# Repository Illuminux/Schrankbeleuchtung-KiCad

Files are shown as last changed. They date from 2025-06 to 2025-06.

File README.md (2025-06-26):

# 💡 Schrankbeleuchtung

Automatisierte LED-Beleuchtung für Schränke, basierend auf einem Raspberry Pi Pico W. Türsensoren aktivieren bei Öffnung die zugeordneten LED-Gruppen über MOSFET-Schaltungen.

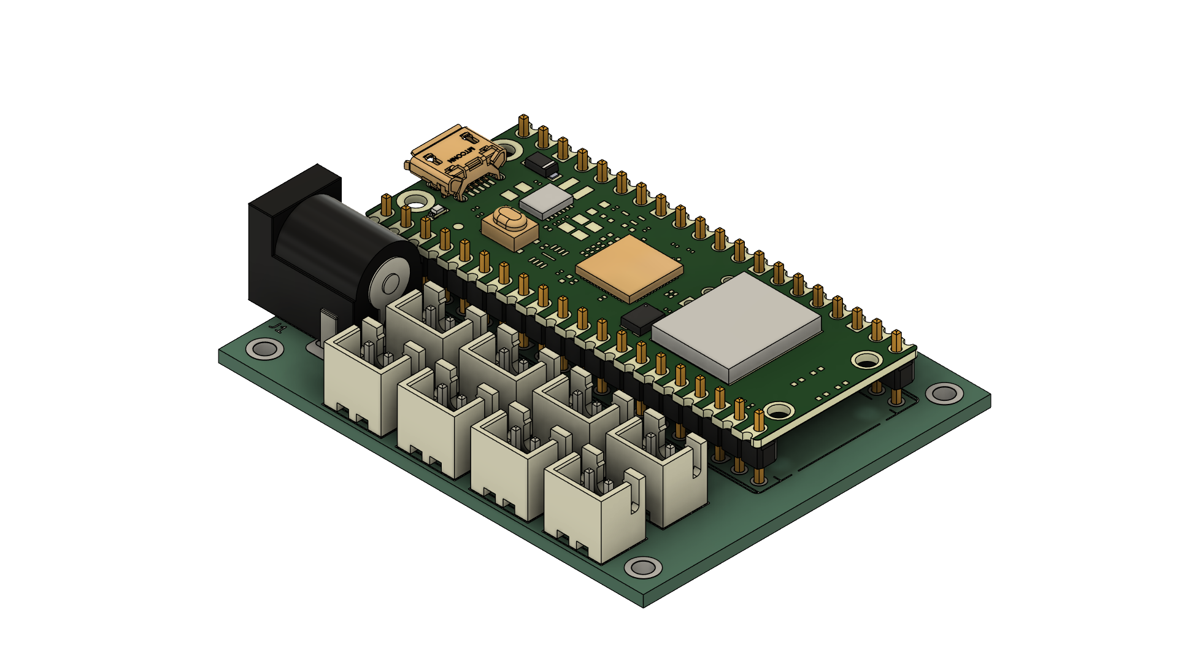
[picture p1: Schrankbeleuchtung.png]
Schaltplanübersicht


---

## 🧩 Features

- Bis zu 4 separat schaltbare LED-Gruppen
- Automatische Steuerung über Magnetsensoren oder Reed-Schalter
- Versorgung mit 12 V DC, intern auf 5 V und 3.3 V geregelt
- Geringe Standby-Leistung durch Low-RDS(on)-MOSFETs
- Erweiterbare Anschlüsse über XH-Steckerleisten

---

## 🔌 GPIO-Belegung (Pico W)

| Funktion | GPIO |
|---|---|
| LED 1 (Q1) | GPIO02 |
| LED 2 (Q2) | GPIO04 |
| LED 3 (Q3) | GPIO05 |
| LED 4 (Q4) | GPIO06 |
| Sensor 1 | GPIO06 |
| Sensor 2 | GPIO07 |
| Sensor 3 | GPIO14 |
| Sensor 4 | GPIO15 |

---

## 🛠 Komponenten (Auszug)

| Bauteil | Typ / Wert | Bestellnummer (Mouser)  |
|---|---|---|
| A1 | Raspberry Pi Pico W | 358-SC0918 |
| U1 | TPS560430XDBVT | 595-TPS560430XDBVT |
| Q1–Q4 | IRLML0030TRPBF | 942-IRLML0030TRPBF |
| R1–R4 | 187 Ω Widerstände | 667-ERA-6AEB1870V |
| R5–R9 | 10 kΩ Pull-Ups | 667-ERA-6APB103V |
| C1–C3 | 10 µF / 22 µF / 0.1 µF  | siehe BOM |
| L1 | 10 µH Spule | 81-LQH44PN100MPRL |
| J2–J9 | XH-Stecker + Buchsen | 306-B2B-XH-AMLFSNP |

Die vollständige Stückliste befindet sich in [Schrankbeleuchtung.xlsx](Schrankbeleuchtung.xlsx)

---

## ⚙️ Inbetriebnahme

1. Platine bestücken (nach Schaltplan aus *Schrankbeleuchtung.pdf*)
2. 12 V Versorgung an J1 anschließen
3. Türsensoren an J2–J5, LEDs an J6–J9 verbinden
4. Firmware auf Pico W flashen (z. B. mit MicroPython)
5. Funktion testen – bei Türöffnung sollten zugehörige LEDs leuchten

---

## 🧠 Firmware-Hinweise

Die Firmware sollte:

- LED-GPIOs als Output setzen
- Sensor-GPIOs mit Pull-Up und Debounce abfragen
- Bei erkanntem Öffnungssignal LEDs aktivieren
- Optional: MQTT-/WLAN-Anbindung via Pico W realisieren

---

## ⚖️ Lizenz

Dieses Projekt steht unter der MIT-Lizenz. Feel free to modify, use & share!

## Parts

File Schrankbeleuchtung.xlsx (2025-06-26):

Reference | Qty | Value | Part No | Mouser
 |  |  |  | Order No | Price / Pice | Price
A1 | 1 | RPiPicoW | SC0918 | 358-SC0918 | 5.70 € | 5.70 €
C1 | 1 | 10µF | GRM21BZ71E106KE5K | 81-GRM21BZ71E106KE5K | 0.30 € | 0.30 €
C2 | 1 | 22µF | GRM21BZ71A226ME5L | 81-GRM21BZ71A226ME5L | 0.27 € | 0.27 €
C3 | 1 | 0.1µF | 0805ZC104JAT2A | 581-0805ZC104JAT2A | 0.27 € | 0.27 €
J1 | 1 | Jack-DC | 694106301002 | 710-694106301002 | 0.87 € | 0.87 €
J2,J3,J4,J5,J6,J7,J8,J9 | 8 | Conn_01x02 | B2B-XH-AMLFSNP | 306-B2B-XH-AMLFSNP | 0.11 € | 0.88 €
L1 | 1 | LQH44PN100MPRL | LQH44PN100MPRL | 81-LQH44PN100MPRL | 0.42 € | 0.42 €
Q1,Q2,Q3,Q4 | 4 | IRLML0030TRPBF | IRLML0030TRPBF | 942-IRLML0030TRPBF | 0.33 € | 1.33 €
R1,R2,R3,R4 | 4 | 187R | ERA-6AEB1870V | 667-ERA-6AEB1870V | 0.09 € | 0.36 €
R5,R6,R7,R8,R9 | 5 | 10k | ERA-6APB103V | 667-ERA-6APB103V | 0.32 € | 1.60 €
R10 | 1 | 3.16k | NT0805DRD073K16L | 603-NT0805DRD073K16L | 0.53 € | 0.53 €
U1 | 1 | TPS560430XDBVT | TPS560430XDBVT | 595-TPS560430XDBVT | 1.25 € | 1.25 €
 |  |  |  | 1St |  | 13.78 €
 |  |  |  | 10 St |  | 129.65 €
Reference | Qty | Value | Part No | Mouser | Price / Pice | Price
J2',J3',J4',J5',J6',J7',J8',J9' | 8 | Buchse | XHP-2 | 306-XHP-2 | 0.10 € | 0.80 €
J2',J3'',J4'',J5'',J6'',J7'',J8'',J9'' | 8 | Pins | SEH-001T-P0.6 | 306-SEH-001T-P0.6 | 0.10 € | 0.80 €
A1' | 2 | Sockel | 68000-220HLF | 649-68000-220HLF | 1.04 € | 2.08 €
 |  |  |  |  |  | 3.68 €
 |  |  |  |  |  | 24.20 €
 |  |  |  |  |  | 17.46 €
 |  |  |  |  |  | 153.85 €
Versand |  |  |  |  |  | 0.00 €
PCB | 1 |  |  |  | 14.80 € | 14.80 €
Schablone | 1 |  |  |  | 9.90 € | 9.90 €
 |  |  |  |  |  | 24.70 €
 |  |  |  |  |  | 28.38 €

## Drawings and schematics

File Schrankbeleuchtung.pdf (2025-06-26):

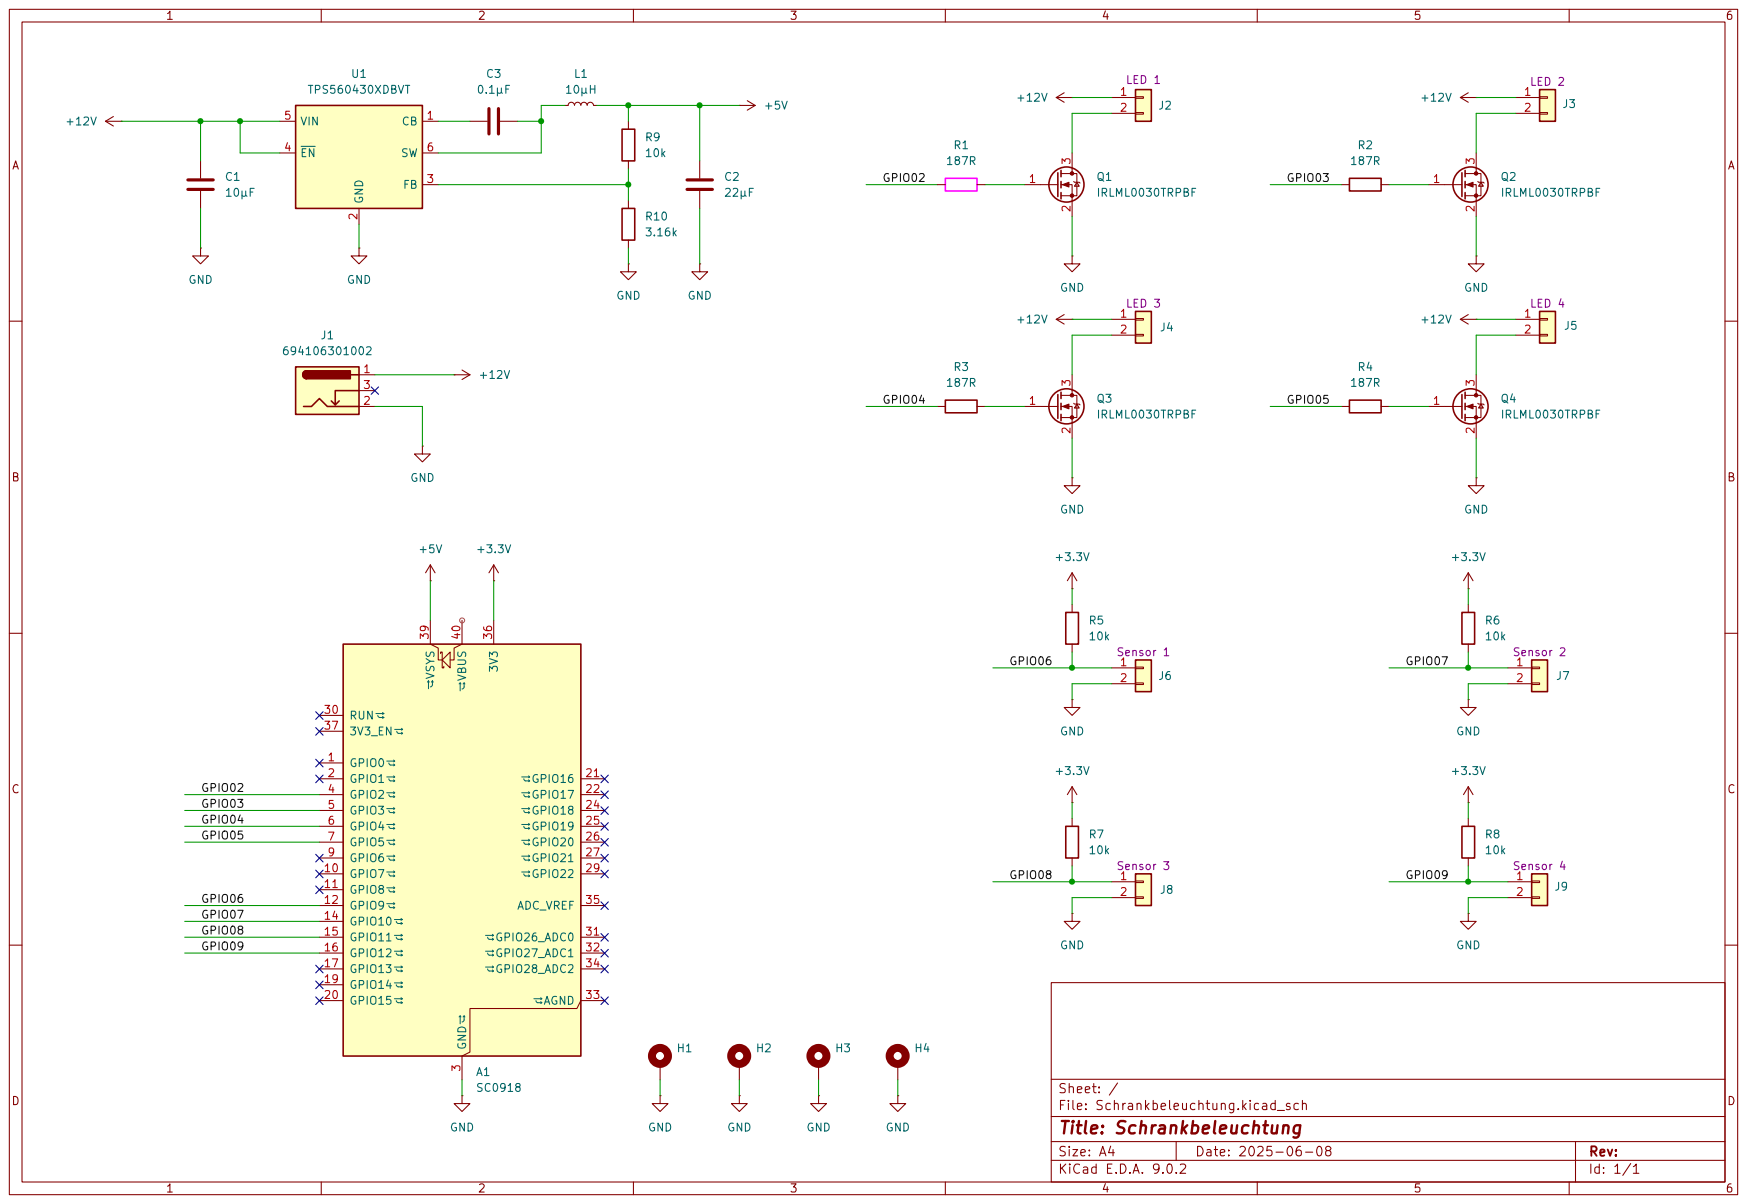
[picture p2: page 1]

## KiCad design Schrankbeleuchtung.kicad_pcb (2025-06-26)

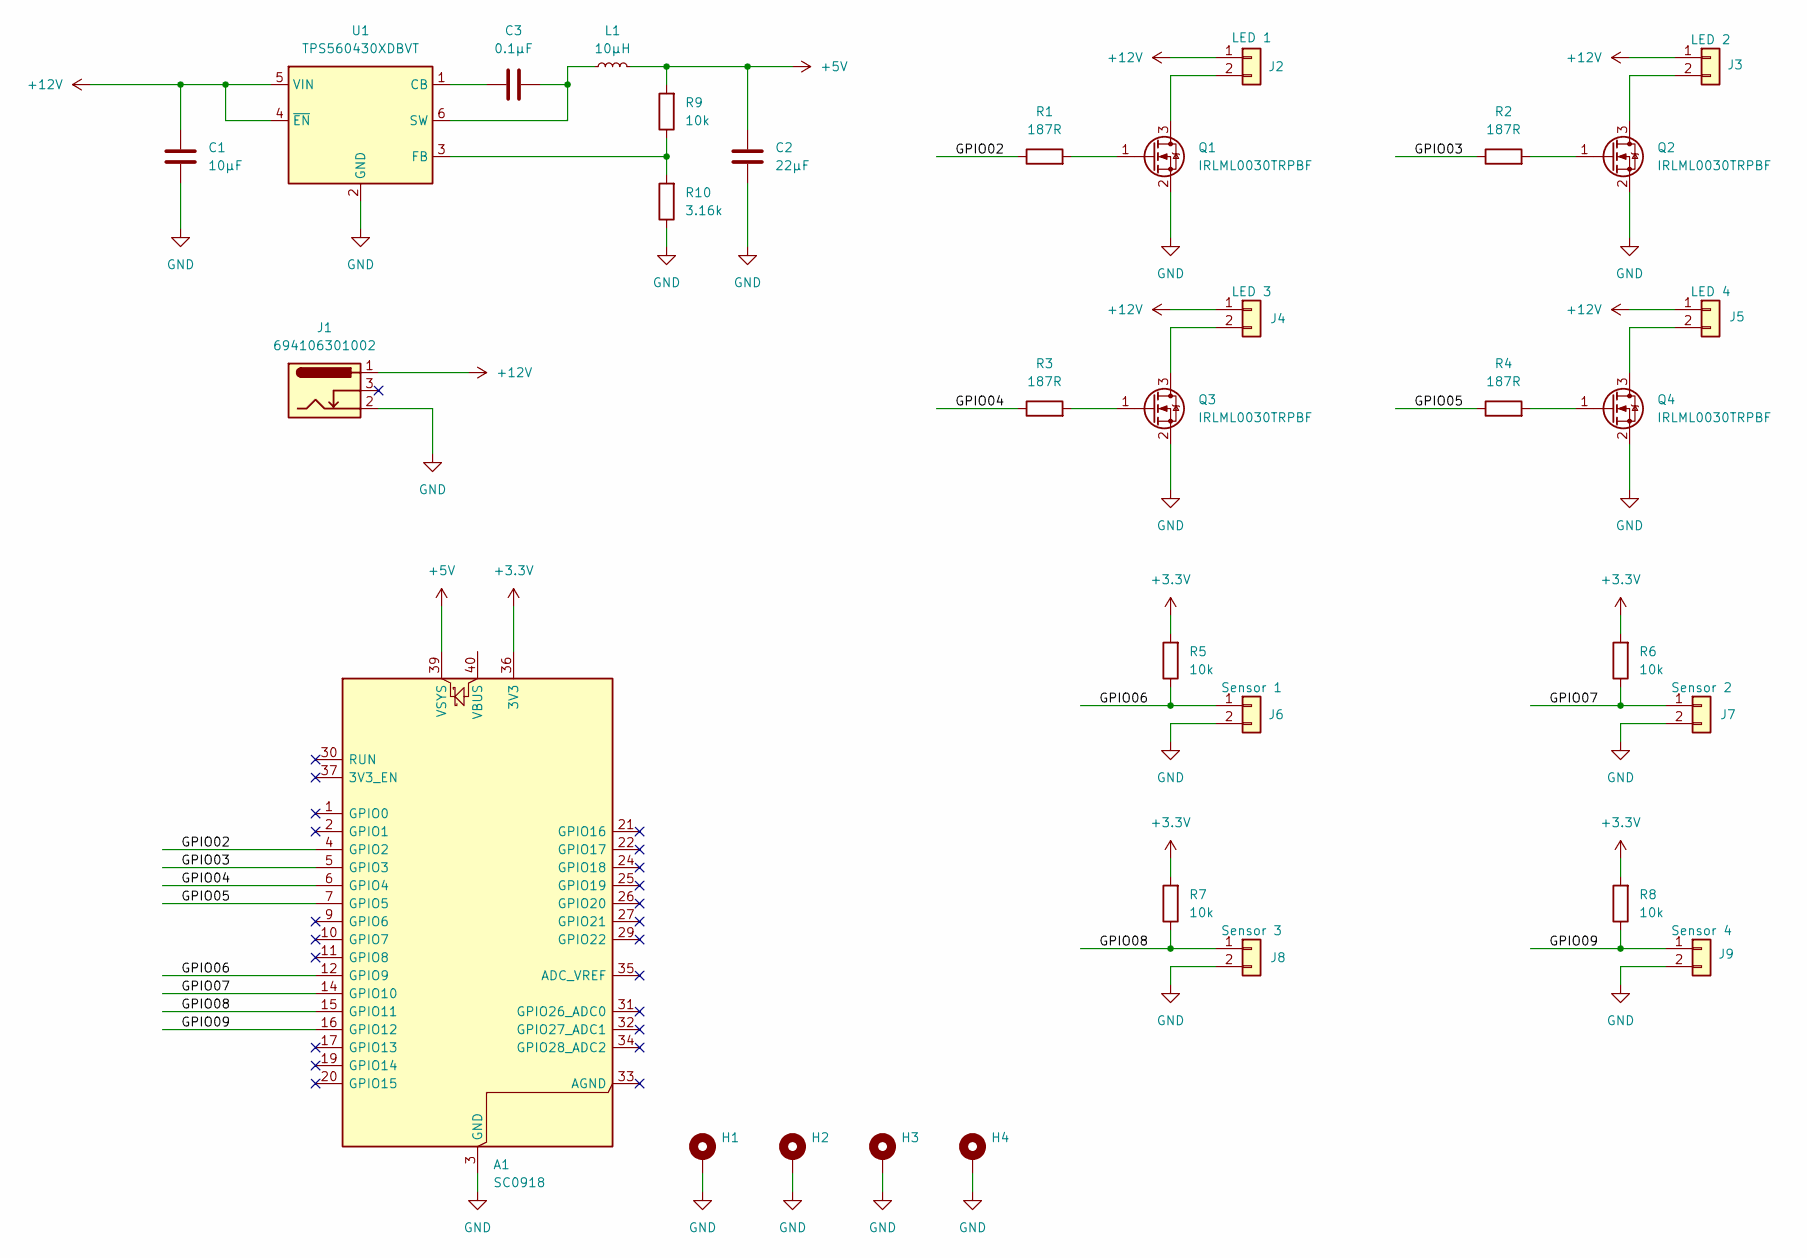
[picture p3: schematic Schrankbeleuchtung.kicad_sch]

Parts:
A1: SC0918; RaspberryPi_Pico_Common_THT
C1: 10µF; C_0805_2012Metric_Pad1.18x1.45mm_HandSolder; Mouser 81-GRM21BZ71E106KE5K
C2: 22µF; C_0805_2012Metric_Pad1.18x1.45mm_HandSolder; Mouser 81-GRM21BZ71A226ME5L
C3: 0.1µF; C_0805_2012Metric_Pad1.18x1.45mm_HandSolder; Mouser 581-0805ZC104JAT2A
H1, H2, H3, H4: MountingHole_Pad; MountingHole_2.2mm_M2_ISO7380_Pad
J1: 694106301002; BarrelJack_Horizontal
J2, J3, J4, J5, J6, J7, J8, J9: B2B-XH-AMLFSNP; JST_XH_B2B-XH-A_1x02_P2.50mm_Vertical
L1: 10µH; L_Cenker_CKCS4030; Mouser 81-LQH44PN100MPRL
Q1, Q2, Q3, Q4: IRLML0030TRPBF; SOT-23
R1, R2, R3, R4: 187R; R_0805_2012Metric_Pad1.20x1.40mm_HandSolder
R5, R6, R7, R8, R9: 10k; R_0805_2012Metric_Pad1.20x1.40mm_HandSolder
R10: 3.16k; R_0805_2012Metric_Pad1.20x1.40mm_HandSolder
U1: TPS560430XDBVT; SOT-23-6_Handsoldering; Mouser 595-TPS560430XDBVT

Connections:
+3.3V: A1.36 (3V3), R5.2, R6.2, R7.2, R8.2
+5V: A1.39 (VSYS), C2.1, L1.2, R9.2
+12V: C1.1, J1.1, J2.1, J3.1, J4.1, J5.1, U1.4 (~EN), U1.5 (VIN)
/GPIO02: A1.4 (GPIO2), R1.1
/GPIO03: A1.5 (GPIO3), R2.1
/GPIO04: A1.6 (GPIO4), R3.1
/GPIO05: A1.7 (GPIO5), R4.1
/GPIO06: A1.12 (GPIO9), J6.1, R5.1
/GPIO07: A1.14 (GPIO10), J7.1, R6.1
/GPIO08: A1.15 (GPIO11), J8.1, R7.1
/GPIO09: A1.16 (GPIO12), J9.1, R8.1
GND: A1.3 (GND), A1.8 (GND), A1.13 (GND), A1.18 (GND), A1.23 (GND), A1.28 (GND), A1.38 (GND), C1.2, C2.2, H1.1, H2.1, H3.1, H4.1, J1.2, J6.2, J7.2, J8.2, J9.2, Q1.2 (S), Q2.2 (S), Q3.2 (S), Q4.2 (S), R10.1, U1.2 (GND)
unnamed: J2.2, Q1.3 (D)
unnamed: J3.2, Q2.3 (D)
unnamed: J4.2, Q3.3 (D)
unnamed: J5.2, Q4.3 (D)
unnamed: Q1.1 (G), R1.2
unnamed: Q2.1 (G), R2.2
unnamed: Q3.1 (G), R3.2
unnamed: Q4.1 (G), R4.2
unnamed: C3.1, U1.1 (CB)
unnamed: R9.1, R10.2, U1.3 (FB)
unnamed: C3.2, L1.1, U1.6 (SW)

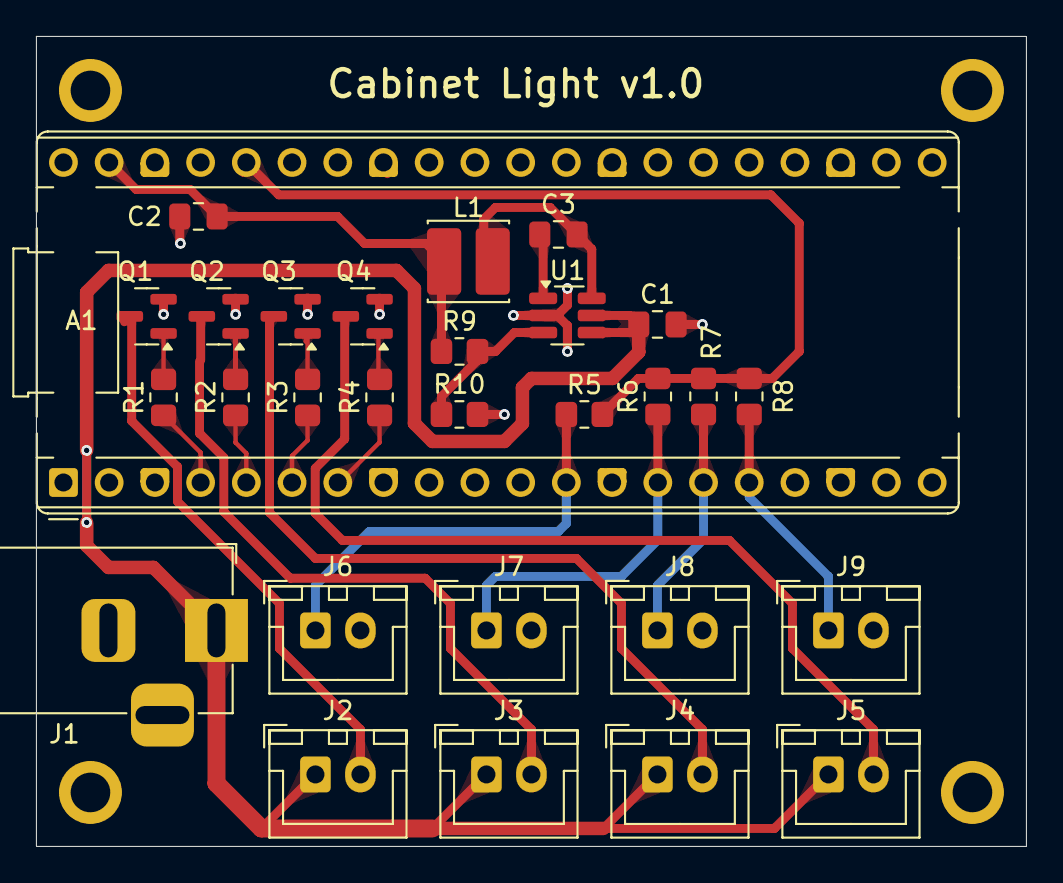
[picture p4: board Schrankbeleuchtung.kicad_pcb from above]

Board: 2 copper layers, 55.0 x 45.0 mm, 33 parts (0 on the bottom side), 23 nets.

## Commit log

2025-06-08 Edit description
    [Schrankbeleuchtung.kicad_pcb, Schrankbeleuchtung.kicad_sch]
2025-06-09 Edit PCB layout
    [Schrankbeleuchtung.kicad_pcb, Schrankbeleuchtung.kicad_sch, Schrankbeleuchtung.xlsx]
2025-06-16 Spannungswandler geändert. Stückliste aktualisiert.
    [Schrankbeleuchtung.kicad_pcb, Schrankbeleuchtung.kicad_sch, Schrankbeleuchtung.xlsx]
2025-06-26 PCB Layoutupdate
    [Schrankbeleuchtung.kicad_pcb, Schrankbeleuchtung.kicad_sch]
2025-06-26 Überarbeitung der Dokumentation
    [Schrankbeleuchtung-B_Cu.gbr, Schrankbeleuchtung-B_Fab.gbr, Schrankbeleuchtung-B_Mask.gbr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]
